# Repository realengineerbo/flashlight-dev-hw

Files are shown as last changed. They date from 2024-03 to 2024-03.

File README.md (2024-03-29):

# Flashlight Dev Board Hardware

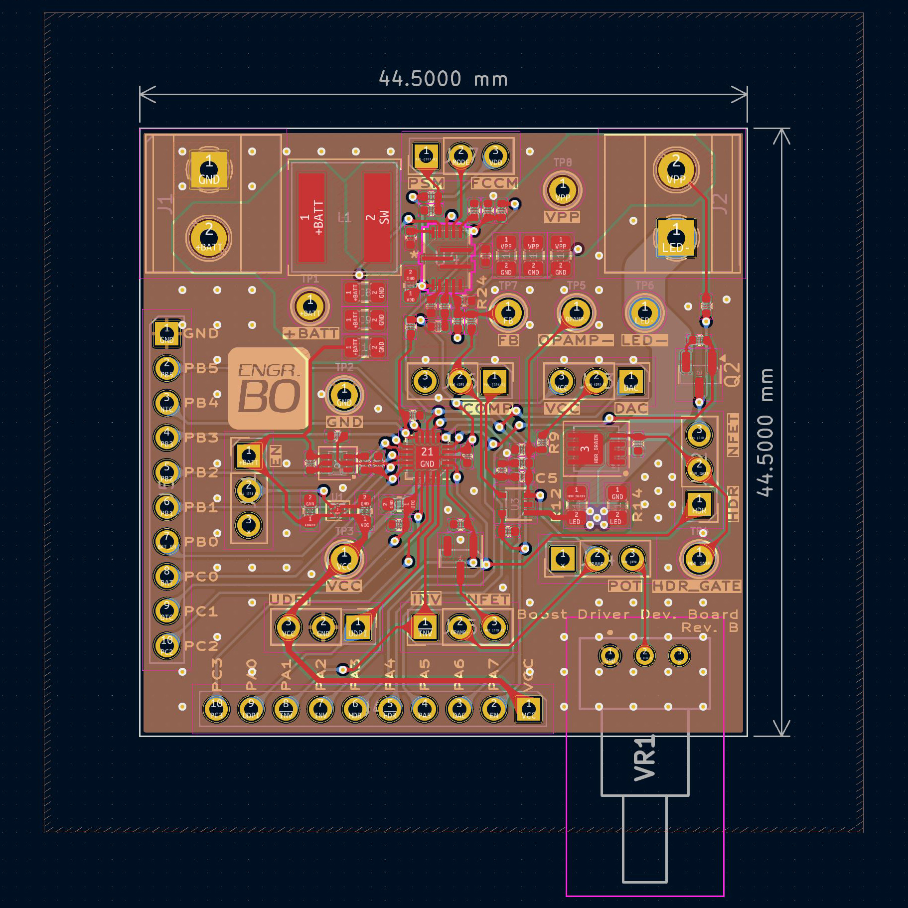
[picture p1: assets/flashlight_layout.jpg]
Dev board layout, rev. B

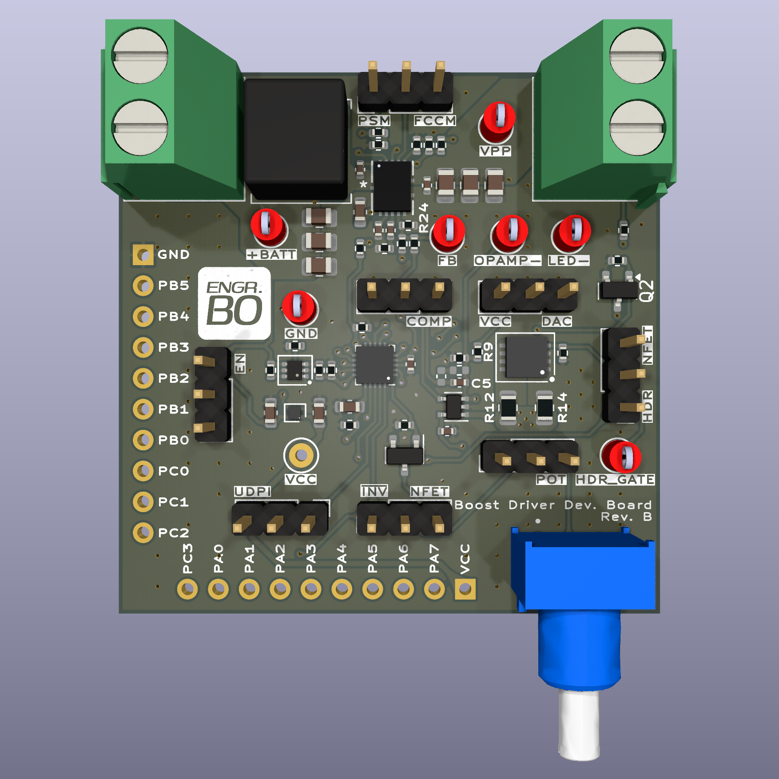
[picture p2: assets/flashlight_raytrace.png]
Dev board render, rev. B


## Introduction

This repository contains design files for the development board for a flashlight boost driver. The test firmware can be found in the [firmware repository](https://github.com/realengineerbo/flashlight-dev-fw).

Also included in the `scripts` subdirectory are Python scripts used to calculate component values during the design process, as well as generate the look-up table for brightness settings.

For a detailed explanation of this project, check out the [video series](https://www.youtube.com/playlist?list=PLYK5tmZIBWtEJjwAFE-49hSeELu9zoAmV) on the [Engineer Bo YouTube channel](https://youtube.com/@engineerbo).

## Features

The development board is design in [KiCad](https://www.kicad.org/), and features the following:

* ATtiny1616 microcontroller
* MP3432 boost converter
* LED current regulation
  * 1R and 10mR current sense resistances, selectable for high dynamic range (HDR)
  * ATtiny1616 DAC controlled current setpoint
  * Current regulation using TLV333/OPA333 op-amp and MP3432 feedback pin
* Power switch multi-click counting
* Temperature sensing
  * NTC thermistor
  * ATtiny1616 internal temperature sensor
* Battery voltage sensing with low current leakage
* Optional potentiometer for current setpoint (highly experimental)
* Test probe hooks
* Headers for all ATtiny1616 pins
* Many jumpers for testing different configurations

## Usage

This development board is meant to serve as a reference for anybody interested in learning about flashlight boost drivers. It's possible to build these boards, but assembly requires reasonable skill and involves less-than-friendly components e.g. DFN, QFN and many 0402 passives.

Instead, I recommend having a look at the schematics, and leave me a comment on [YouTube](https://www.youtube.com/playlist?list=PLYK5tmZIBWtEJjwAFE-49hSeELu9zoAmV) if you have any questions.

## Hardware Revisions

### Revision A

This is the original design built for testing, and includes a couple of issues:

* GPIO driven P-channel MOSFET for HDR MOSFET gate drive
* MP3432 UVLO not configured
* Wrong footprint for NTC thermistor

These issues and their fixes are explained in detail in the [video series](https://www.youtube.com/playlist?list=PLYK5tmZIBWtEJjwAFE-49hSeELu9zoAmV).

### Revision B

Revision B fixes the issues in Revision A:

* GPIO driven N-channel MOSFET for HDR MOSFET gate drive
* Added MP3432 UVLO

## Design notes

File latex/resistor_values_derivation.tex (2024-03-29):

\documentclass[landscape,twocolumn]{article} 

\usepackage{amsmath}
\usepackage[european resistors]{circuitikz}
\usepackage{geometry}
\usepackage{siunitx}

\geometry{left=4cm, right=4cm}
\pagestyle{empty}

\begin{document}

\begin{center}
    \scalebox{1.3}{
        \begin{circuitikz}

            % Draw resistors
            \draw (0,3) to [R, l=$R_a$, i_=$i_a$] (0,0);
            \draw (0,0) to [R, l=$R_b$, i_=$i_b$] (0,-3);
            \draw (3,0) to [R, l=$R_c$, i=$i_c$] (0,0);

            % Draw labels
            \draw (0,3) node[vcc]{$V_{out}$};

            \draw (0,-3) node[ground]{};

            \node [circ]() at (0,0) {};
            \draw (0,0) to (-1,0) node[ocirc]{};
            \draw (-2,0) node {$V_{FB}=1V$};

            \node [ocirc]() at (3,0) {};
            \draw (3.8,0) node {$V_{opamp}$};

        \end{circuitikz}
    }
\end{center}

\newpage

Where $R_a$ is known (e.g. $\SI{750}{\kilo\ohm}$), and:
\begin{gather*}
    V_{out} \propto V_{opamp}^{-1} \\
    V_{opamp,min}\le V_{opamp}\le V_{opamp,max} \\
    V_{out,min}\le V_{out}\le V_{out,max}
\end{gather*}

Currents through resistors:
\begin{align*}
    i_a & = \frac{V_{out} - 1}{R_a} \quad & i_b & = \frac{1}{R_b} \quad & i_c & = \frac{V_{opamp} - 1}{R_c}
\end{align*}

Using Kirchhoff's Current Law:
\begin{gather*}
    i_a + i_c = i_b \\
    \frac{V_{out} - 1}{R_a} + \frac{V_{opamp} - 1}{R_c} = \frac{1}{R_b}
\end{gather*}

Substituting:
\begin{gather*}
    \frac{V_{out,max} - 1}{R_a} + \frac{V_{opamp,min} - 1}{R_c} = \frac{1}{R_b} \\
    \frac{V_{out,min} - 1}{R_a} + \frac{V_{opamp,max} - 1}{R_c} = \frac{1}{R_b} \\
    \frac{V_{out,max} - 1}{R_a} + \frac{V_{opamp,min} - 1}{R_c} = \frac{V_{out,min} - 1}{R_a} + \frac{V_{opamp,max} - 1}{R_c}
\end{gather*}

Finally:
\begin{gather*}
    R_c = R_a\frac{V_{opamp,max} - V_{opamp,min}}{V_{out,max} - V_{out,min}}
\end{gather*}

\end{document}

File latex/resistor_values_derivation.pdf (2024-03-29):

## Vout

## Where Ra is known (e.g. 750 kΩ), and:

Vout ∝ V

−1
opamp

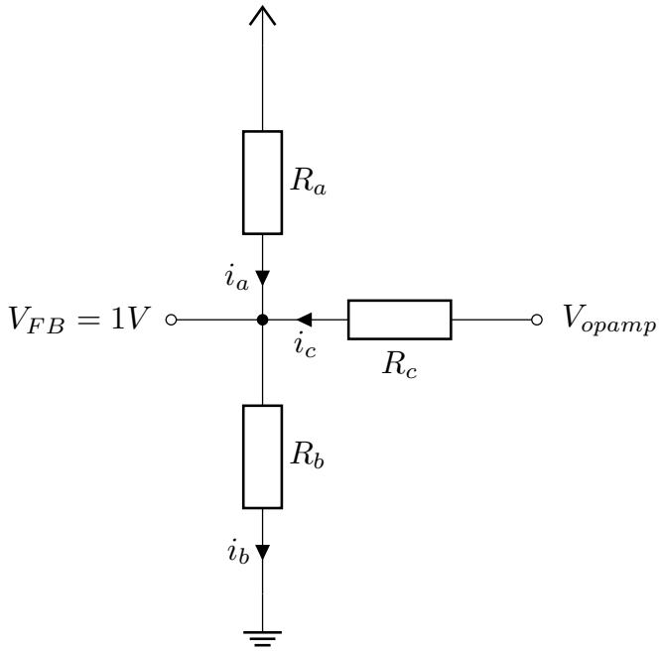
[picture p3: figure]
Vopamp

Vopamp,min ≤ Vopamp ≤ Vopamp,max

Vout,min ≤ Vout ≤ Vout,max

## Currents through resistors:

ia =

Vout − 1
Ra

ib =

1
Rb

ic =

Vopamp − 1
Rc

## Using Kirchhoff’s Current Law:

## ia + ic = ib

Vout − 1
Ra

+

Vopamp − 1
Rc

=

1
Rb

## Substituting:

Vout,max − 1
Ra

+

Vopamp,min − 1
Rc

=

1
Rb

Vout,min − 1
Ra

+

Vopamp,max − 1
Rc

=

1
Rb

Vout,max − 1
Ra

+

Vopamp,min − 1
Rc

=

Vout,min − 1
Ra

+

Vopamp,max − 1
Rc

## Finally:

## Rc = Ra

Vopamp,max − Vopamp,min

Vout,max − Vout,min

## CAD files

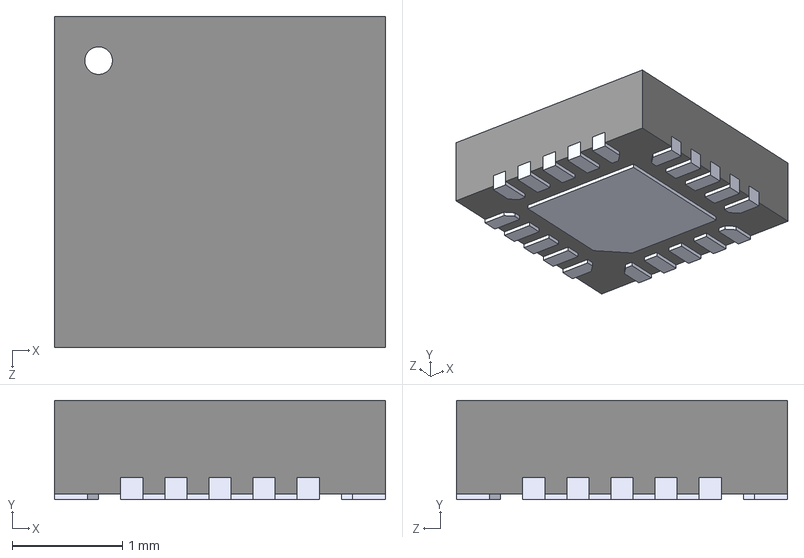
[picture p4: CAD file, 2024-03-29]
components/ATTINY1616-MFR.step
3.00 x 0.9 x 3.00 mm

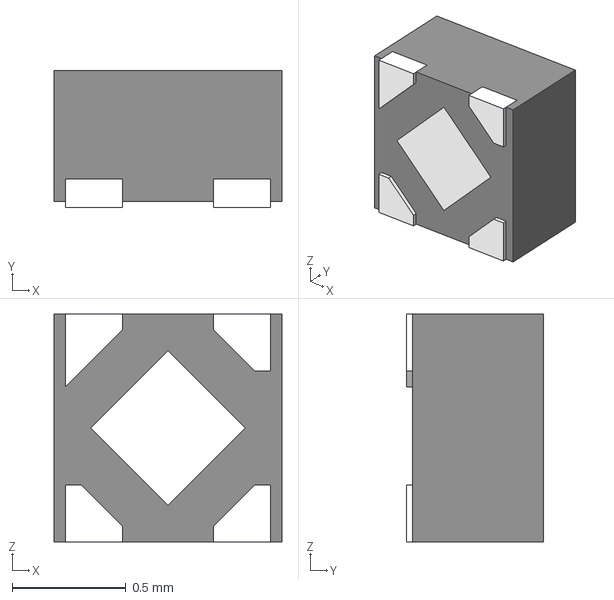
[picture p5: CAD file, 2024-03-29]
components/NCP114AMX330TCG.stp
1.00 x 0.6 x 1.00 mm

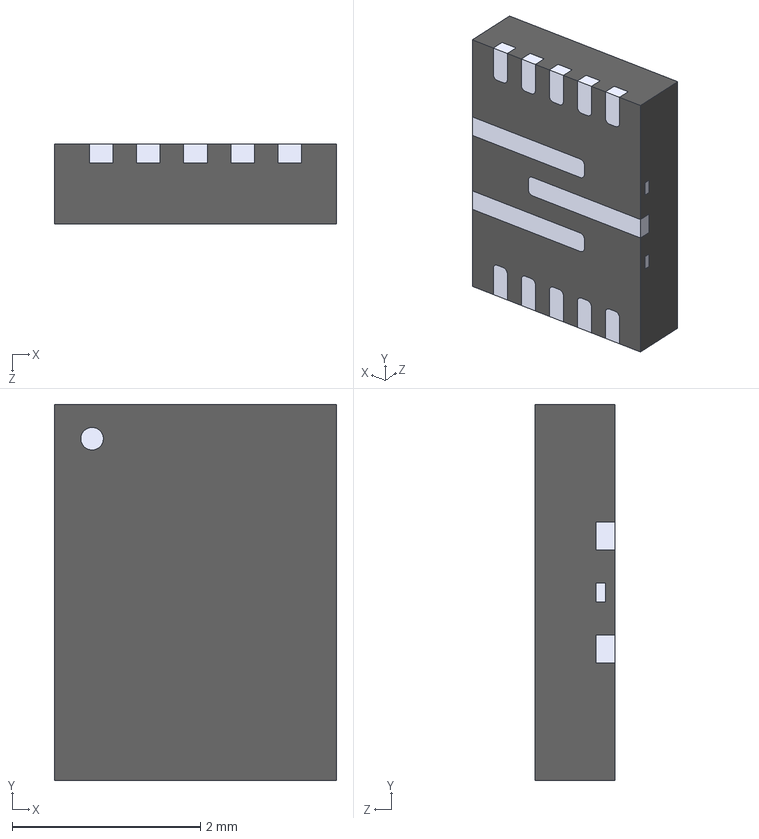
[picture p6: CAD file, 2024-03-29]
components/MP3429GL.step
3.00 x 4.00 x 0.85 mm

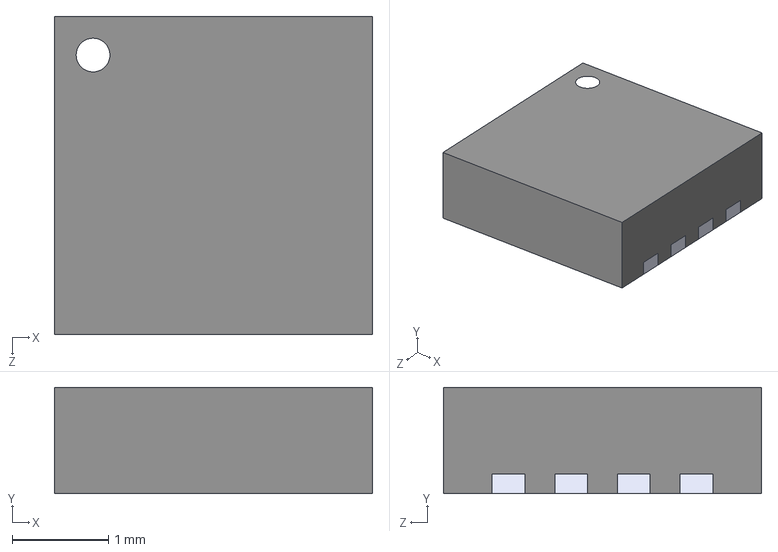
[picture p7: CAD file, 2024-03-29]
components/PG-TSDSON-8FL.step
3.30 x 1.10 x 3.30 mm

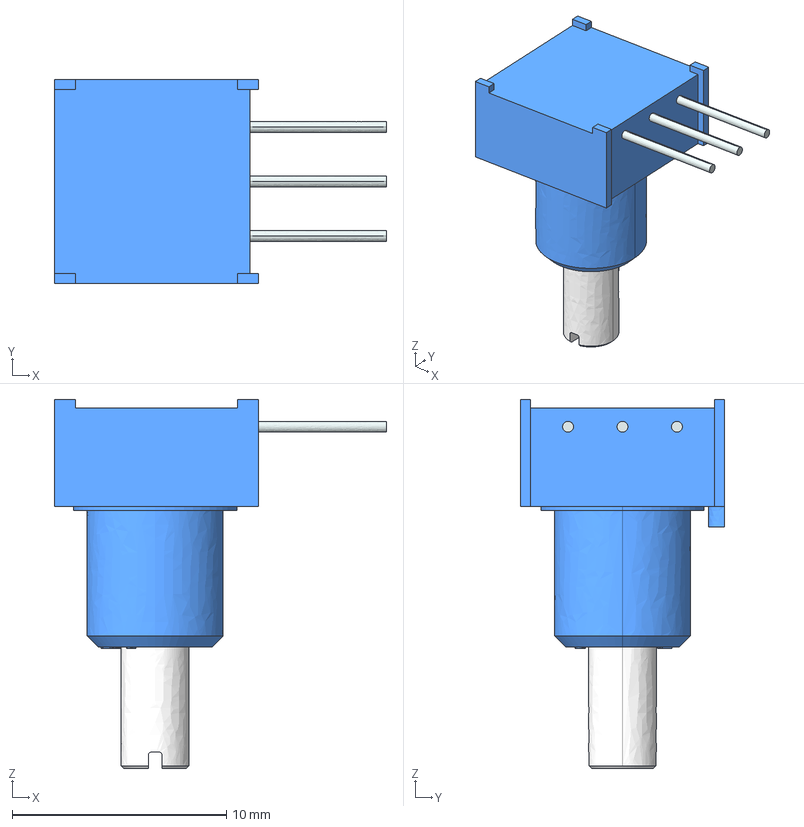
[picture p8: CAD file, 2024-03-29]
components/3310C-001-104L.stp
15.5 x 9.53 x 17.2 mm

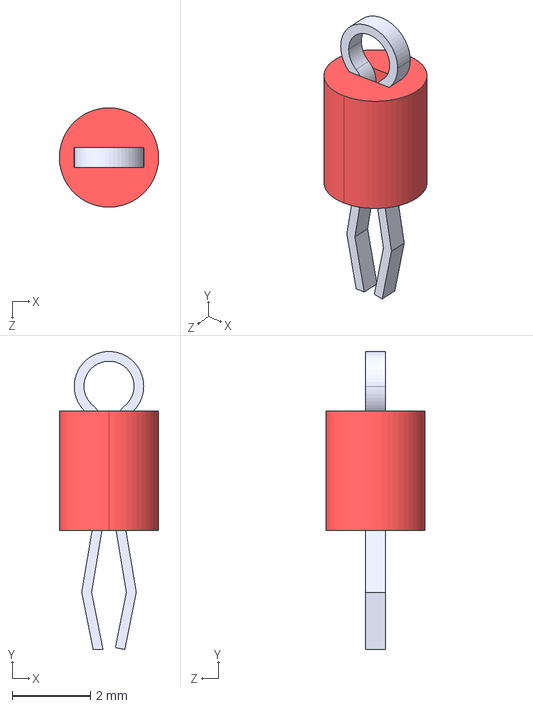
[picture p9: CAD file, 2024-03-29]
components/5000.step
2.54 x 7.62 x 2.54 mm

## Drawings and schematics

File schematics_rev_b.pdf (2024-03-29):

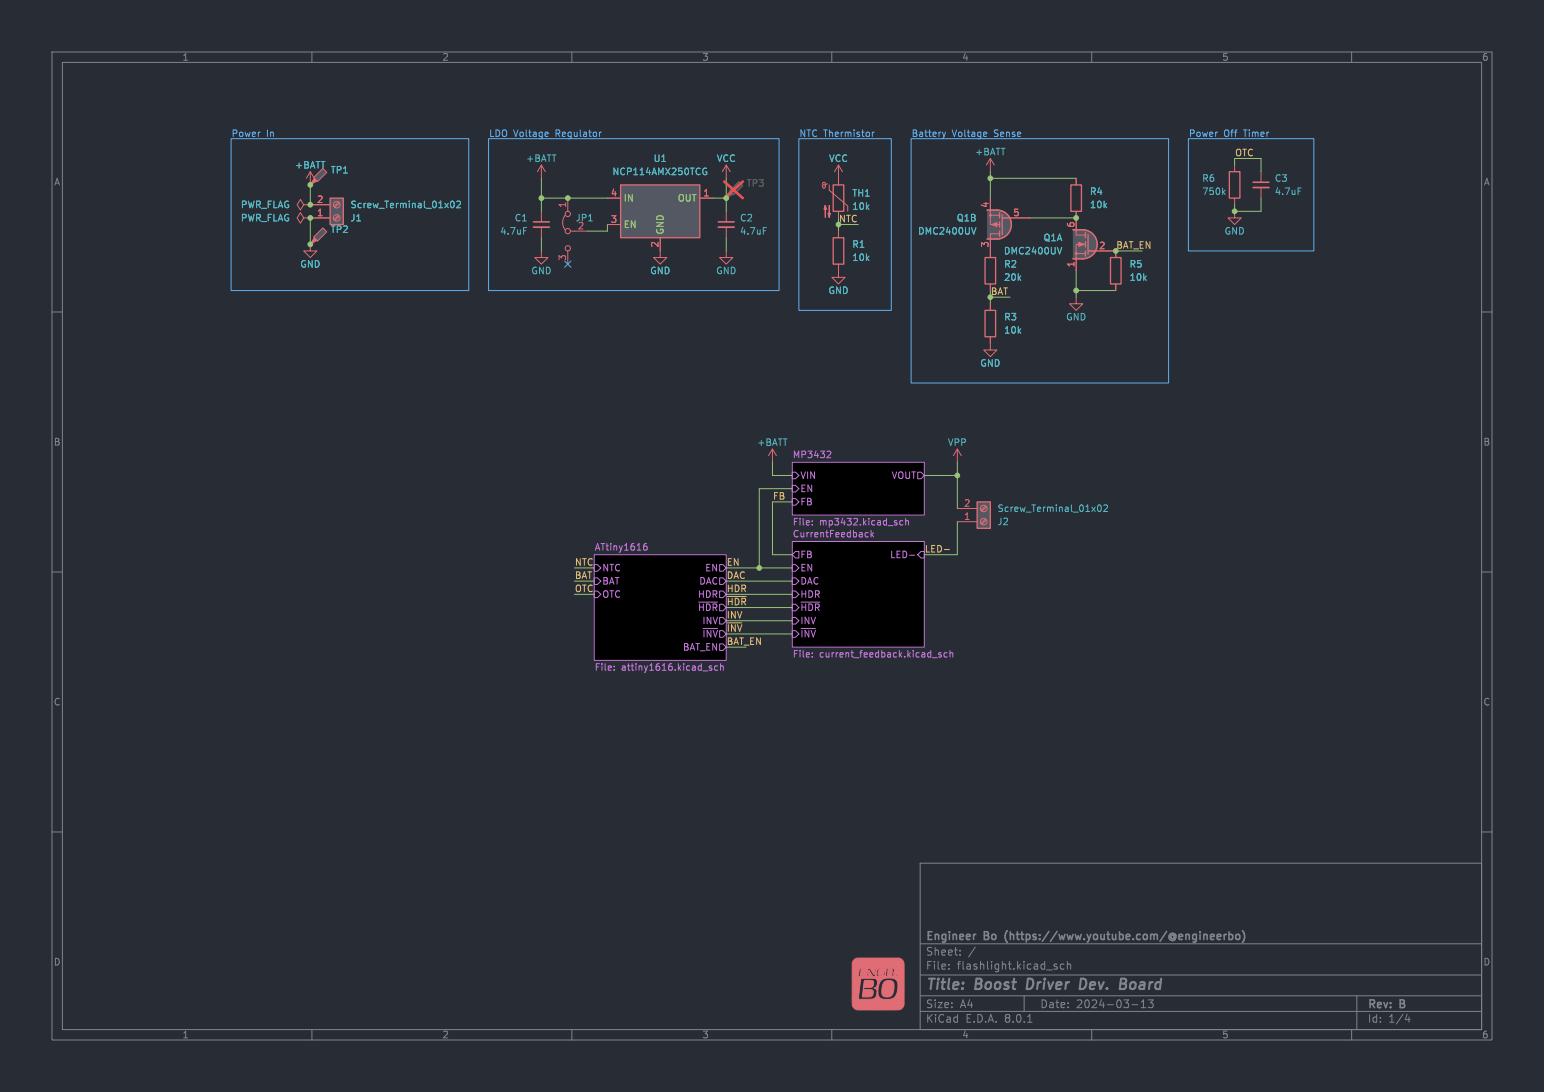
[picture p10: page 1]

Id: 1/4 Title: Boost Driver Dev. Board

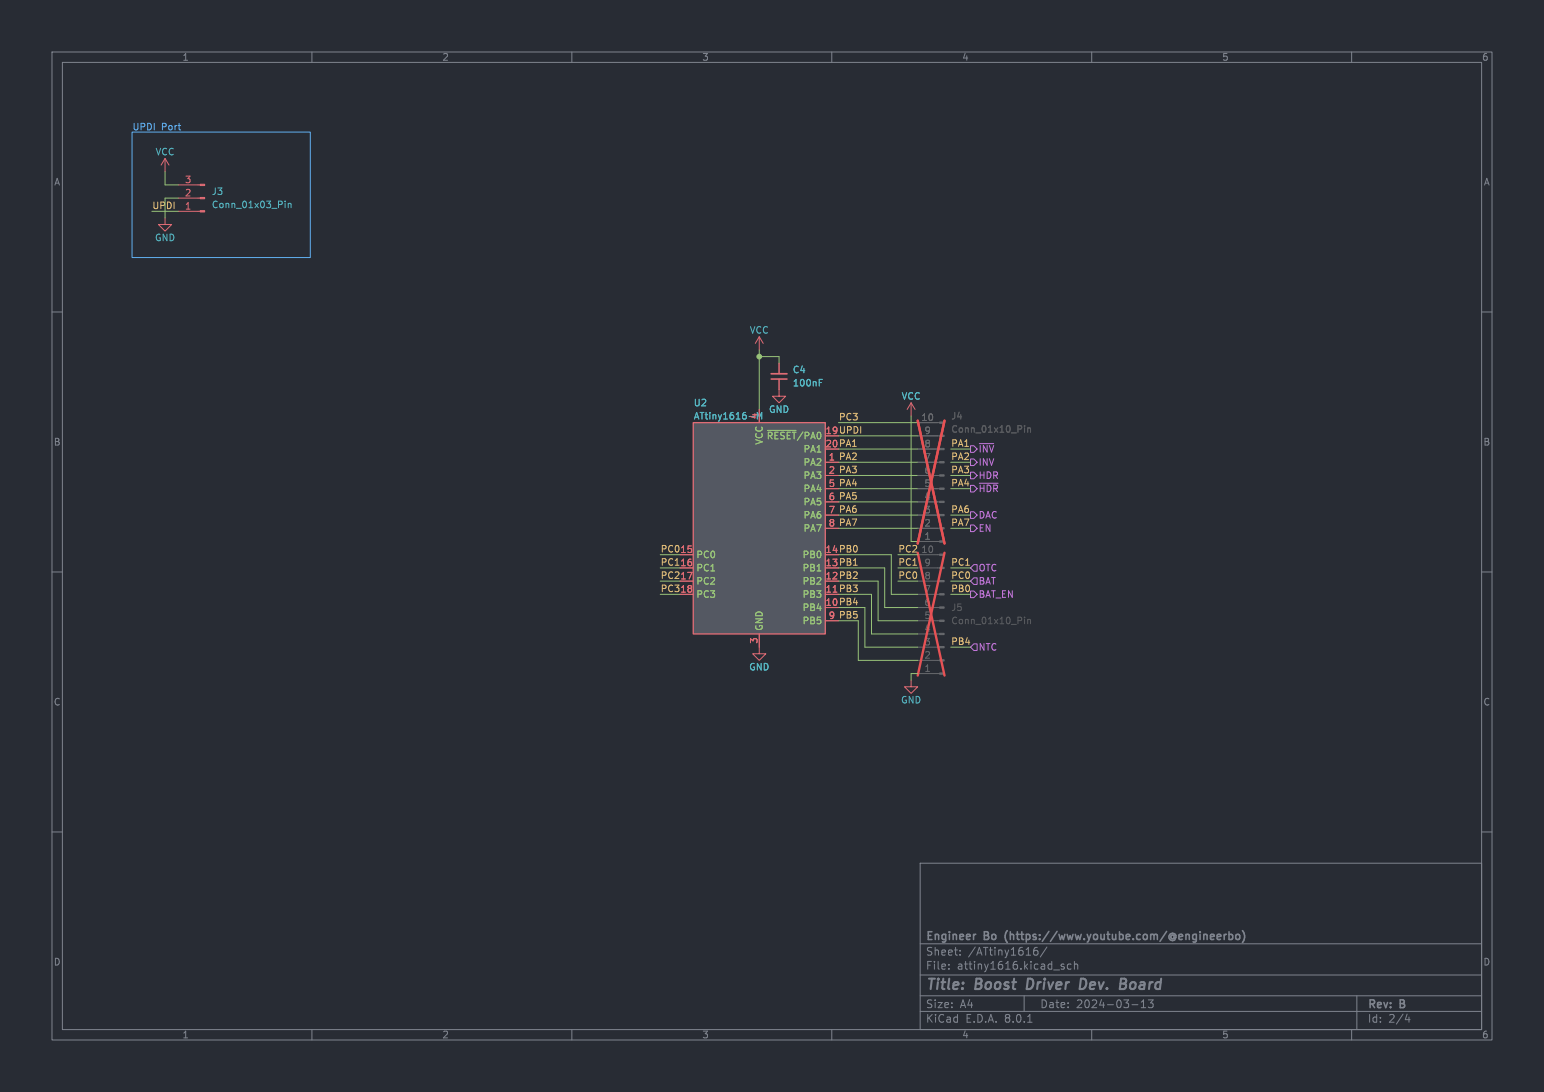
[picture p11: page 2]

File: attiny1616.kicad_sch Sheet: /ATtiny1616/
Id: 2/4 Title: Boost Driver Dev. Board

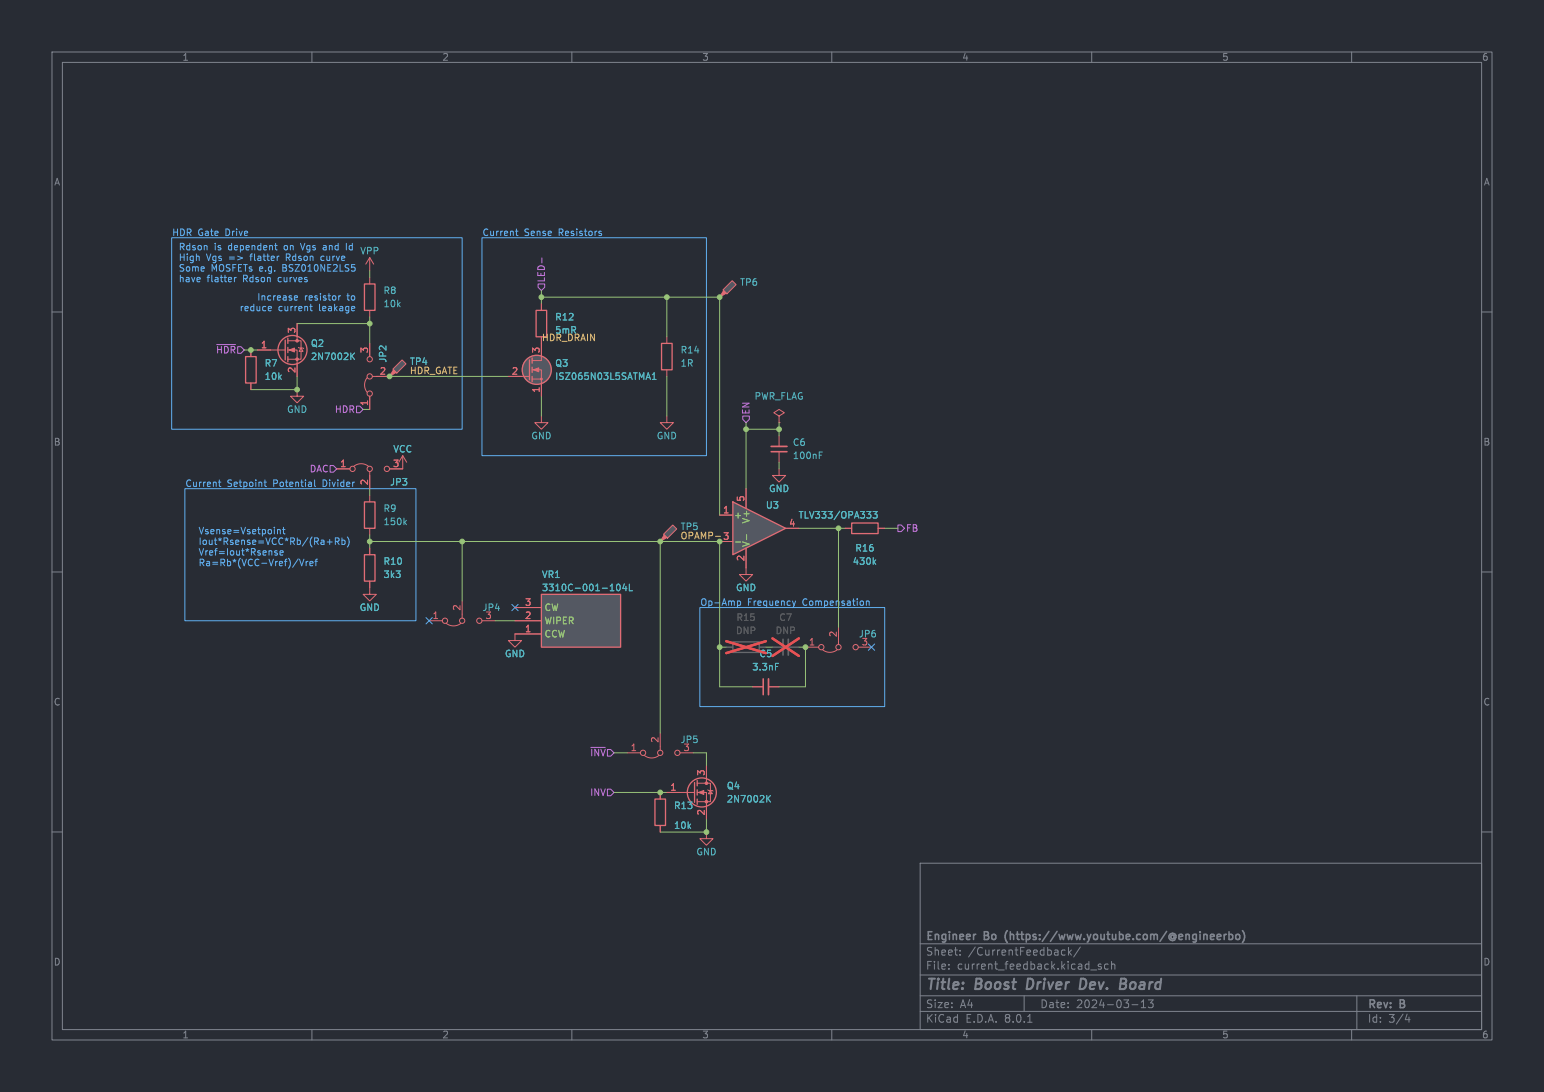
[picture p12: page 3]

Id: 3/4 Title: Boost Driver Dev. Board

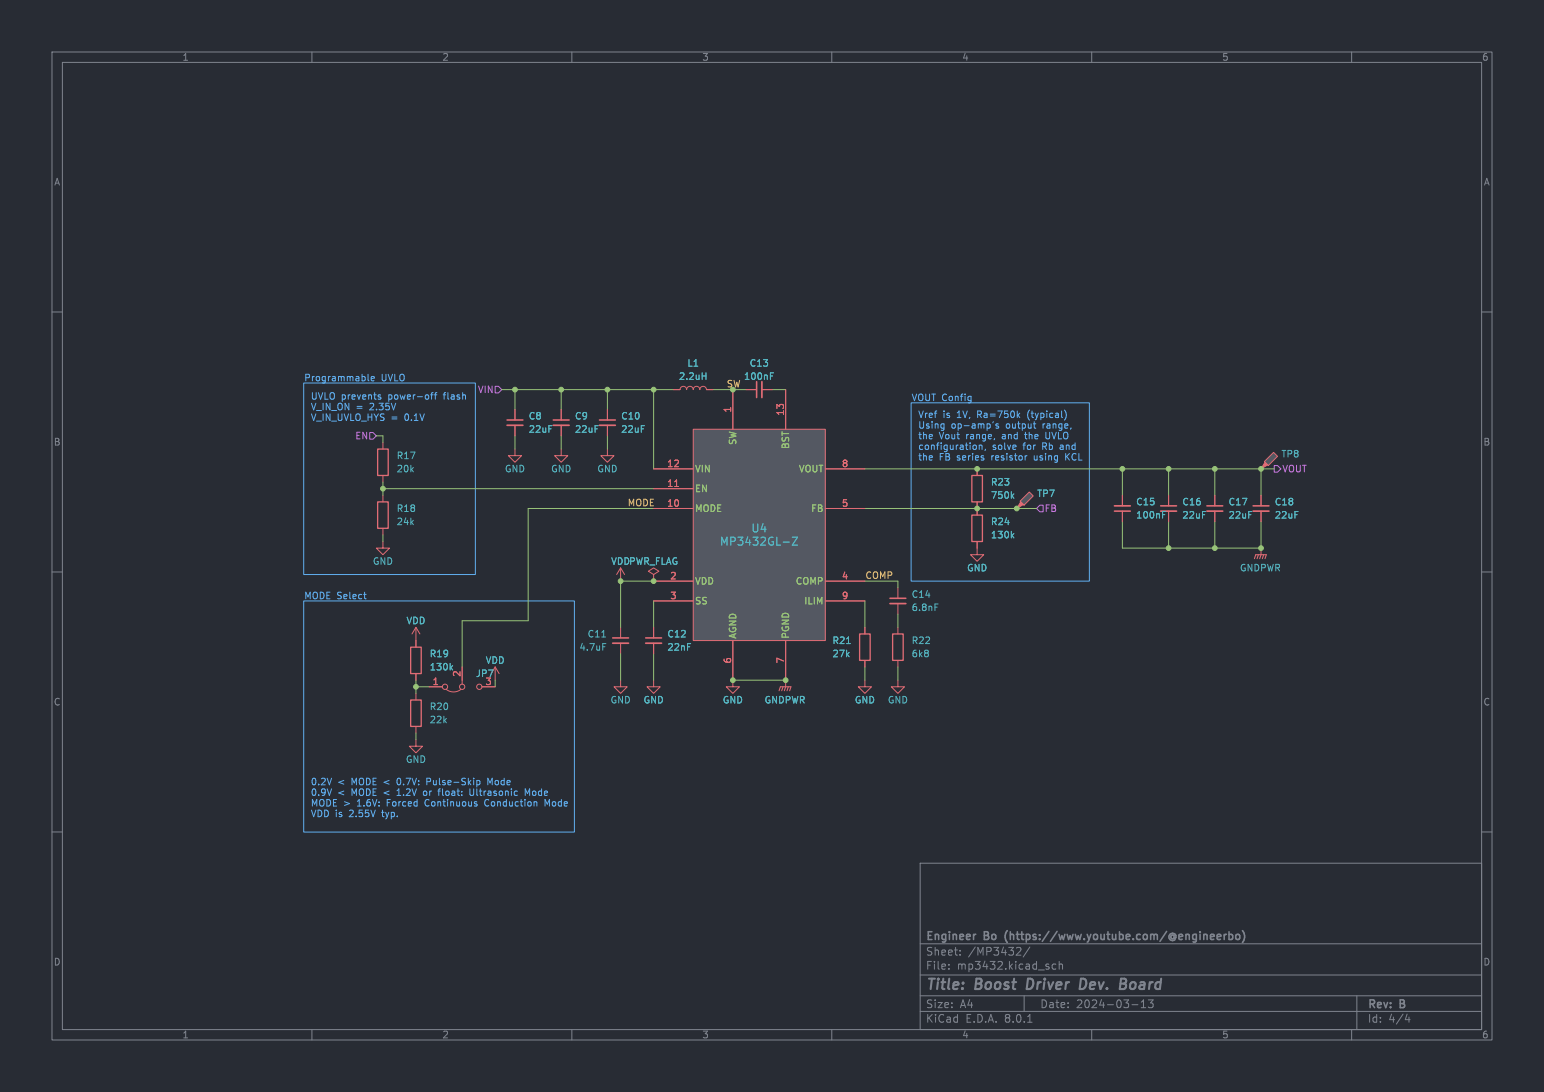
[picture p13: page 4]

1 MODE 10 EN 11 BST 13 VDD 2 SS 3 VOUT 8

the Vout range, and the UVLO

Id: 4/4 Title: Boost Driver Dev. Board

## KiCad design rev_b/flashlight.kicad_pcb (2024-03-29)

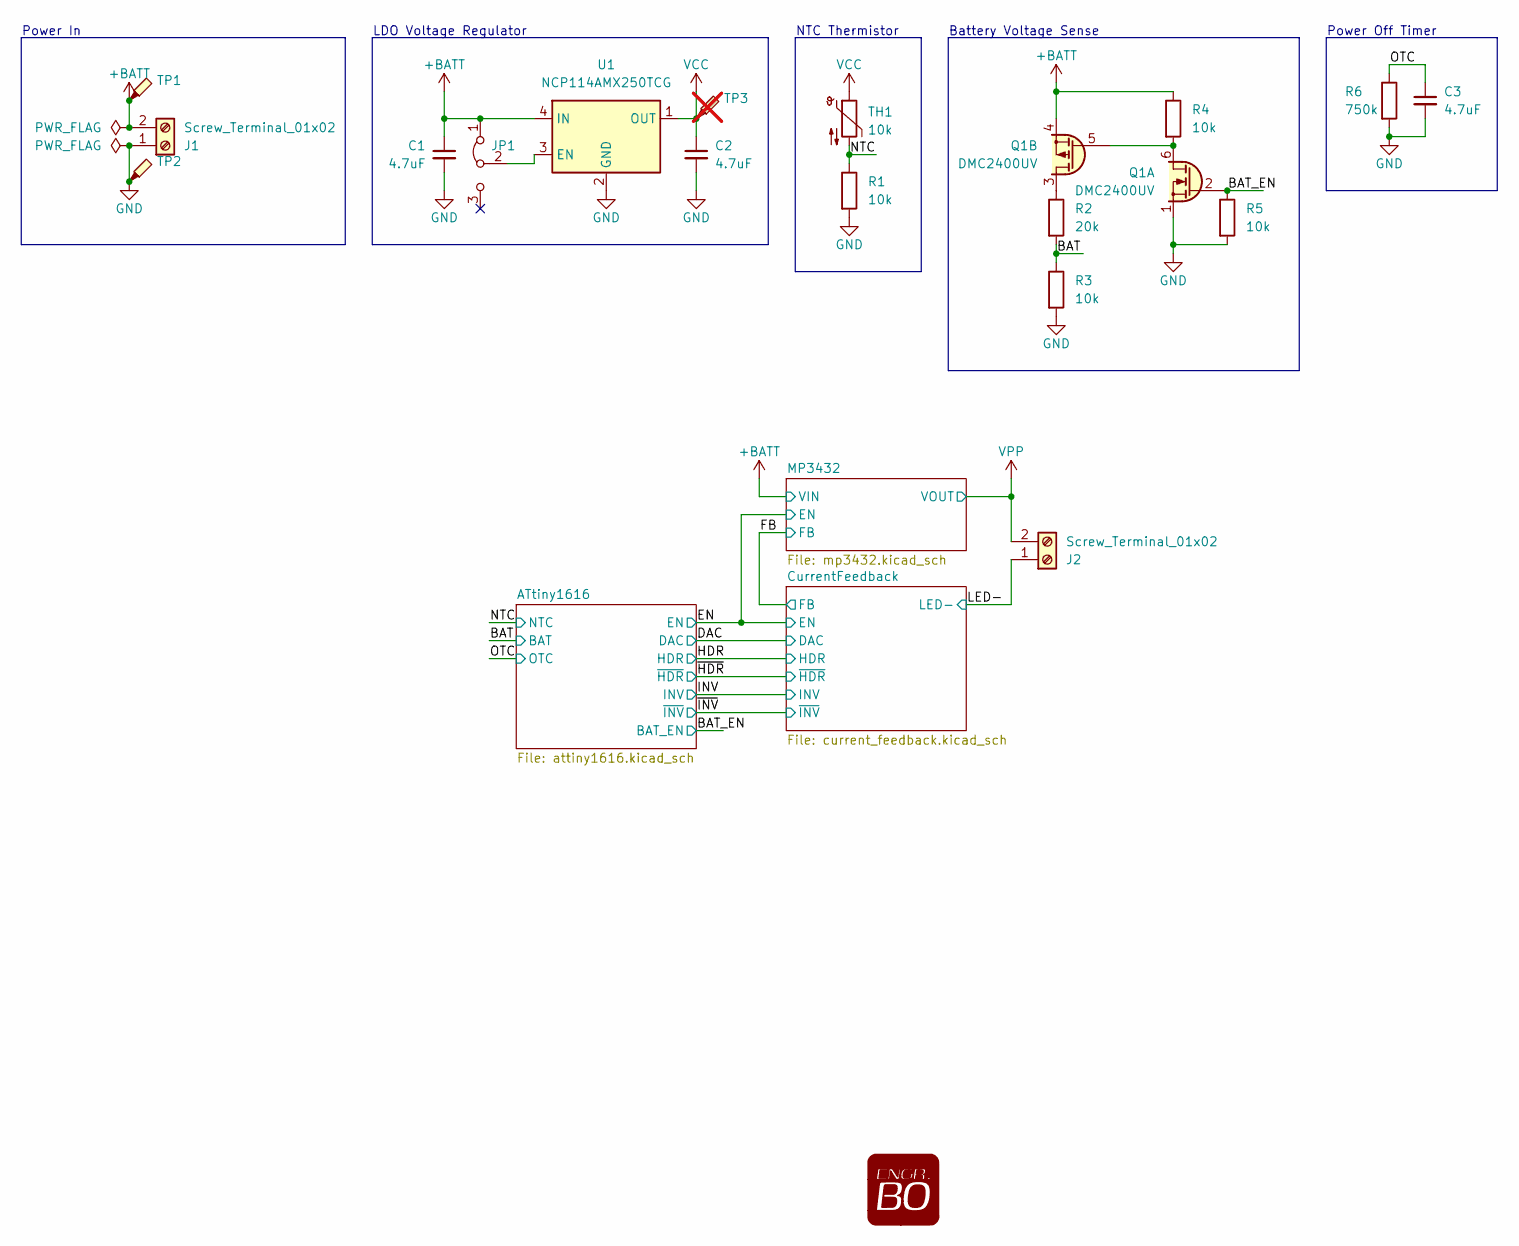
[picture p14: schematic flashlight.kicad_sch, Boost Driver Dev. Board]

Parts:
C1, C2, C3: 4.7uF; C_0603_1608Metric; Tolerance X5R; Voltage 16V
J1, J2: Screw_Terminal_01x02; TerminalBlock_Phoenix_MKDS-1,5-2_1x02_P5.00mm_Horizontal
JP1: Jumper_3_Bridged12; PinHeader_1x03_P2.54mm_Vertical
LOGO1: LOGO; logo_6mm
Q1: DMC2400UV; SOT-563
R1, R3, R4, R5: 10k; R_0402_1005Metric; Tolerance 1%
R2: 20k; R_0402_1005Metric; Tolerance 1%
R6: 750k; R_0402_1005Metric; Tolerance 1%
TH1: 10k; R_0402_1005Metric; PartNumber NCP15XH103F03RC
TP1, TP2: TestPoint_Probe; TestPoint_Keystone_5000-5004_Miniature; PartNumber RH-5000
TP3: TestPoint_Probe; TestPoint_Keystone_5000-5004_Miniature; PartNumber RH-5000; not fitted
U1: NCP114AMX250TCG; OnSemi_XDFN4-1EP_1.0x1.0mm_EP0.52x0.52mm; PartNumber NCP114AMX250TCG

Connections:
+BATT: C1.1, J1.2, JP1.1 (A), Q1.4 (S2), R4.1, TP1.1, U1.4 (IN); also elsewhere on the board
/BAT: R2.2, R3.1; also elsewhere on the board
/BAT_EN: Q1.2 (G1), R5.1; also elsewhere on the board
/LED-: J2.1; also elsewhere on the board
/NTC: R1.1, TH1.2; also elsewhere on the board
/OTC: C3.1, R6.1; also elsewhere on the board
GND: C1.2, C2.2, C3.2, J1.1, Q1.1 (S1), R1.2, R3.2, R5.2, R6.2, TP2.1, U1.2 (GND), U1.5 (GND); also elsewhere on the board
unnamed: JP1.2 (C), U1.3 (EN)
unnamed: Q1.5 (G2), Q1.6 (D1), R4.2
unnamed: Q1.3 (D2), R2.1
VCC: C2.1, TH1.1, TP3.1, U1.1 (OUT); also elsewhere on the board
VPP: J2.2; also elsewhere on the board

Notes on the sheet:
NTC Thermistor
Battery Voltage Sense
LDO Voltage Regulator
Power In
Power Off Timer

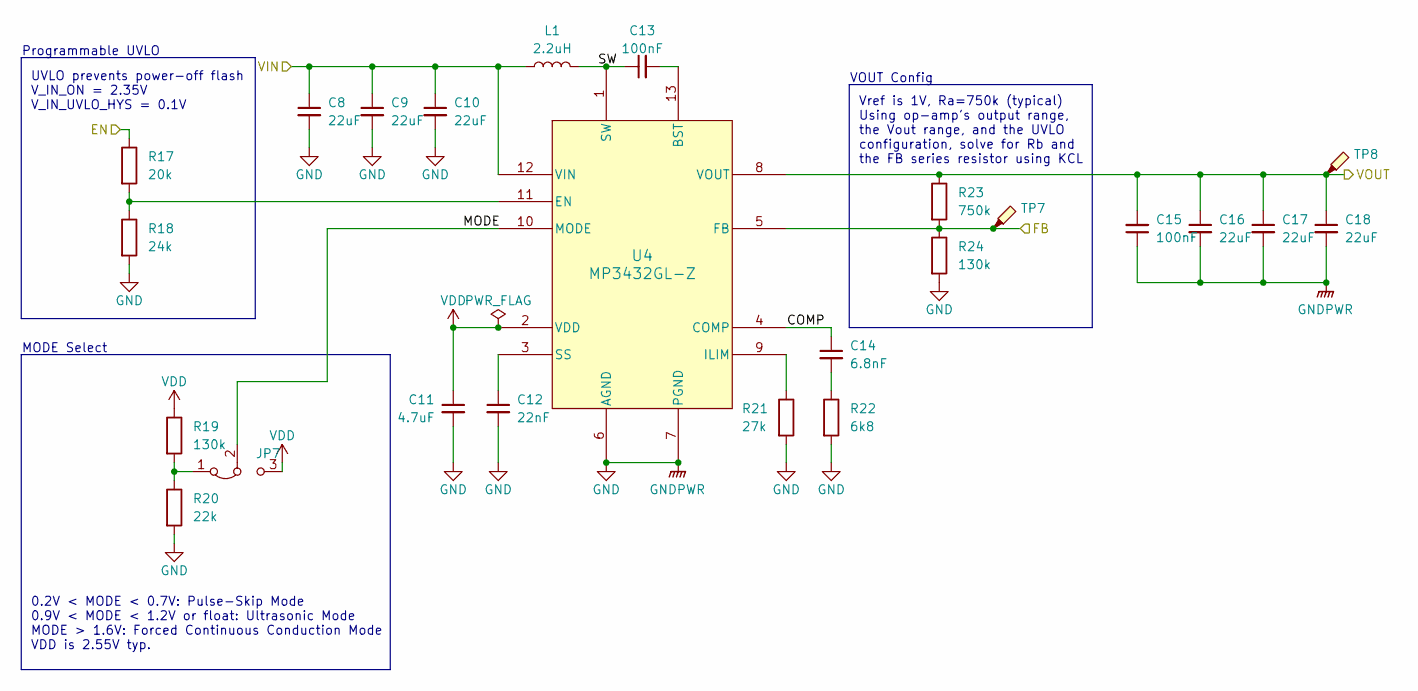
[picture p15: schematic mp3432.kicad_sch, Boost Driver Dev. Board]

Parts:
C8, C9, C10, C16, C17, C18: 22uF; C_0805_2012Metric; Tolerance X5R; Voltage 25V
C11: 4.7uF; C_0603_1608Metric; Tolerance X5R; Voltage 16V
C12: 22nF; C_0402_1005Metric
C13, C15: 100nF; C_0402_1005Metric
C14: 6.8nF; C_0402_1005Metric
JP7: Jumper_3_Bridged12; PinHeader_1x03_P2.54mm_Vertical
L1: 2.2uH; L_Coilcraft_XAL7070-XXX; PartNumber XAL7070-222MEC
R17: 20k; R_0402_1005Metric; Tolerance 1%
R18: 24k; R_0402_1005Metric; Tolerance 1%
R19, R24: 130k; R_0402_1005Metric; Tolerance 1%
R20: 22k; R_0402_1005Metric; Tolerance 1%
R21: 27k; R_0402_1005Metric; Tolerance 1%
R22: 6k8; R_0402_1005Metric; Tolerance 1%
R23: 750k; R_0402_1005Metric; Tolerance 1%
TP7, TP8: TestPoint_Probe; TestPoint_Keystone_5000-5004_Miniature; PartNumber RH-5000
U4: MP3432GL-Z; QFN-13_MP3431_MNP; PartNumber MP3432GL-Z

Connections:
+BATT: C8.1, C9.1, C10.1, L1.1, U4.12 (VIN); also elsewhere on the board
/EN: R17.1; also elsewhere on the board
/FB: R23.2, R24.1, TP7.1, U4.5 (FB); also elsewhere on the board
/MP3432/COMP: C14.1, U4.4 (COMP)
/MP3432/MODE: JP7.2 (C), U4.10 (MODE)
/MP3432/SW: C13.1, L1.2, U4.1 (SW)
GND: C8.2, C9.2, C10.2, C11.2, C12.2, C15.1, C16.2, C17.2, C18.2, R18.2, R20.2, R21.2, R22.2, R24.2, U4.6 (AGND), U4.7 (PGND); also elsewhere on the board
unnamed: C14.2, R22.1
unnamed: JP7.1 (A), R19.2, R20.1
unnamed: C13.2, U4.13 (BST)
unnamed: R17.2, R18.1, U4.11 (EN)
unnamed: R21.1, U4.9 (ILIM)
unnamed: C12.1, U4.3 (SS)
VDD: C11.1, JP7.3 (B), R19.1, U4.2 (VDD)
VPP: C15.2, C16.1, C17.1, C18.1, R23.1, TP8.1, U4.8 (VOUT); also elsewhere on the board

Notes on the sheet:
Vref is 1V, Ra=750k (typical) Using op-amp's output range, the Vout range, and the UVLO configuration, solve for Rb and the FB series resistor using KCL
0.2V < MODE < 0.7V: Pulse-Skip Mode 0.9V < MODE < 1.2V or float: Ultrasonic Mode MODE > 1.6V: Forced Continuous Conduction Mode VDD is 2.55V typ.
MODE Select
UVLO prevents power-off flash V_IN_ON = 2.35V V_IN_UVLO_HYS = 0.1V
Programmable UVLO
VOUT Config

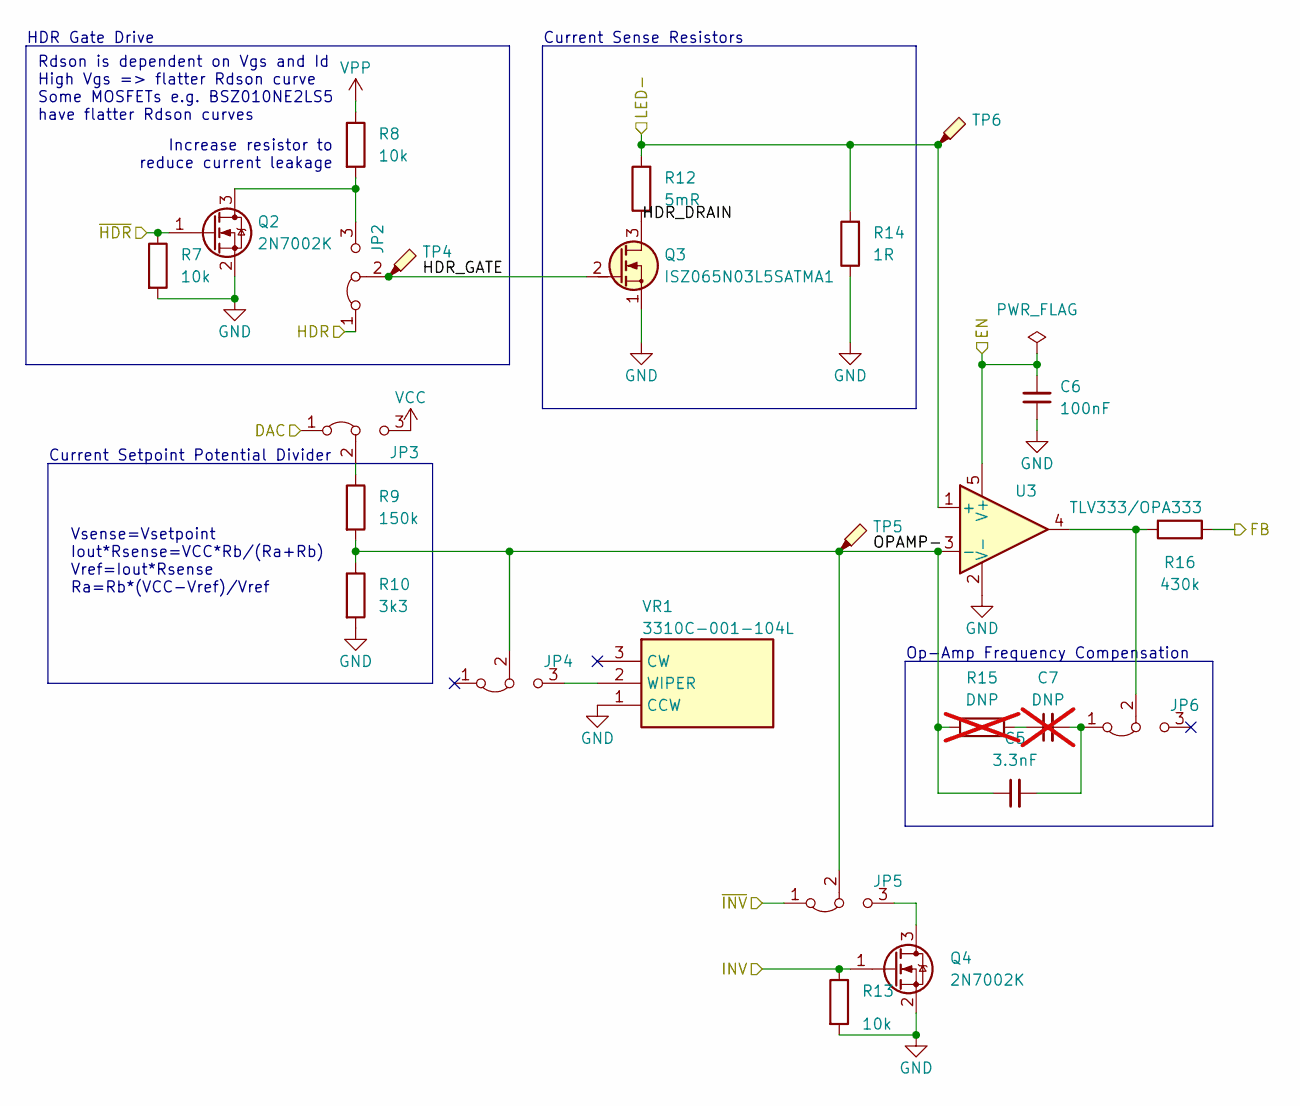
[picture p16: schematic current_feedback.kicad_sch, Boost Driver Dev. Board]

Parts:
C5: 3.3nF; C_0402_1005Metric; Tolerance C0G
C6: 100nF; C_0402_1005Metric
C7: DNP; C_0402_1005Metric; Tolerance C0G; not fitted
JP2, JP3, JP4, JP5, JP6: Jumper_3_Bridged12; PinHeader_1x03_P2.54mm_Vertical
Q2, Q4: 2N7002K; SOT-23
Q3: ISZ065N03L5SATMA1; Infineon_PG_TSDSON-8_FL; PartNumber ISZ065N03L5SATMA1
R7, R8, R13: 10k; R_0402_1005Metric; Tolerance 1%
R9: 150k; R_0402_1005Metric; Tolerance 1%
R10: 3k3; R_0402_1005Metric; Tolerance 1%
R12: 5mR; R_0805_2012Metric; Tolerance 1%
R14: 1R; R_0805_2012Metric; Tolerance 1%
R15: DNP; R_0402_1005Metric; Tolerance 1%; not fitted
R16: 430k; R_0402_1005Metric; Tolerance 1%
TP4, TP5, TP6: TestPoint_Probe; TestPoint_Keystone_5000-5004_Miniature; PartNumber RH-5000
U3: TLV333/OPA333; SOT-353_SC-70-5; PartNumber TLV333IDCKR
VR1: 3310C-001-104L; 3310C001503L; Mouser Part Number 652-3310C-001-104L

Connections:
/CurrentFeedback/HDR_DRAIN: Q3.3 (D), R12.1
/CurrentFeedback/HDR_GATE: JP2.2 (C), Q3.2 (G), TP4.1
/CurrentFeedback/OPAMP-: C5.1, JP4.2 (C), JP5.2 (C), R9.2, R10.1, R15.1, TP5.1, U3.3 (-)
/DAC: JP3.1 (A); also elsewhere on the board
/EN: C6.2, U3.5 (V+); also elsewhere on the board
/FB: R16.2; also elsewhere on the board
/HDR: JP2.1 (A); also elsewhere on the board
/INV: Q4.1 (G), R13.1; also elsewhere on the board
/LED-: R12.2, R14.2, TP6.1, U3.1 (+); also elsewhere on the board
/~HDR: Q2.1 (G), R7.1; also elsewhere on the board
/~INV: JP5.1 (A); also elsewhere on the board
GND: C6.1, Q2.2 (S), Q3.1 (S), Q4.2 (S), R7.2, R10.2, R13.2, R14.1, U3.2 (V-), VR1.1 (CCW); also elsewhere on the board
unnamed: C7.1, R15.2
unnamed: JP2.3 (B), Q2.3 (D), R8.2
unnamed: JP3.2 (C), R9.1
unnamed: JP4.3 (B), VR1.2 (WIPER)
unnamed: JP5.3 (B), Q4.3 (D)
unnamed: C5.2, C7.2, JP6.1 (A)
unnamed: JP6.2 (C), R16.1, U3.4
VCC: JP3.3 (B); also elsewhere on the board
VPP: R8.1; also elsewhere on the board

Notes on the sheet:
Current Setpoint Potential Divider
HDR Gate Drive
Vsense=Vsetpoint Iout*Rsense=VCC*Rb/(Ra+Rb) Vref=Iout*Rsense Ra=Rb*(VCC-Vref)/Vref
Increase resistor to reduce current leakage
Rdson is dependent on Vgs and Id High Vgs => flatter Rdson curve Some MOSFETs e.g. BSZ010NE2LS5 have flatter Rdson curves
Op-Amp Frequency Compensation
Current Sense Resistors

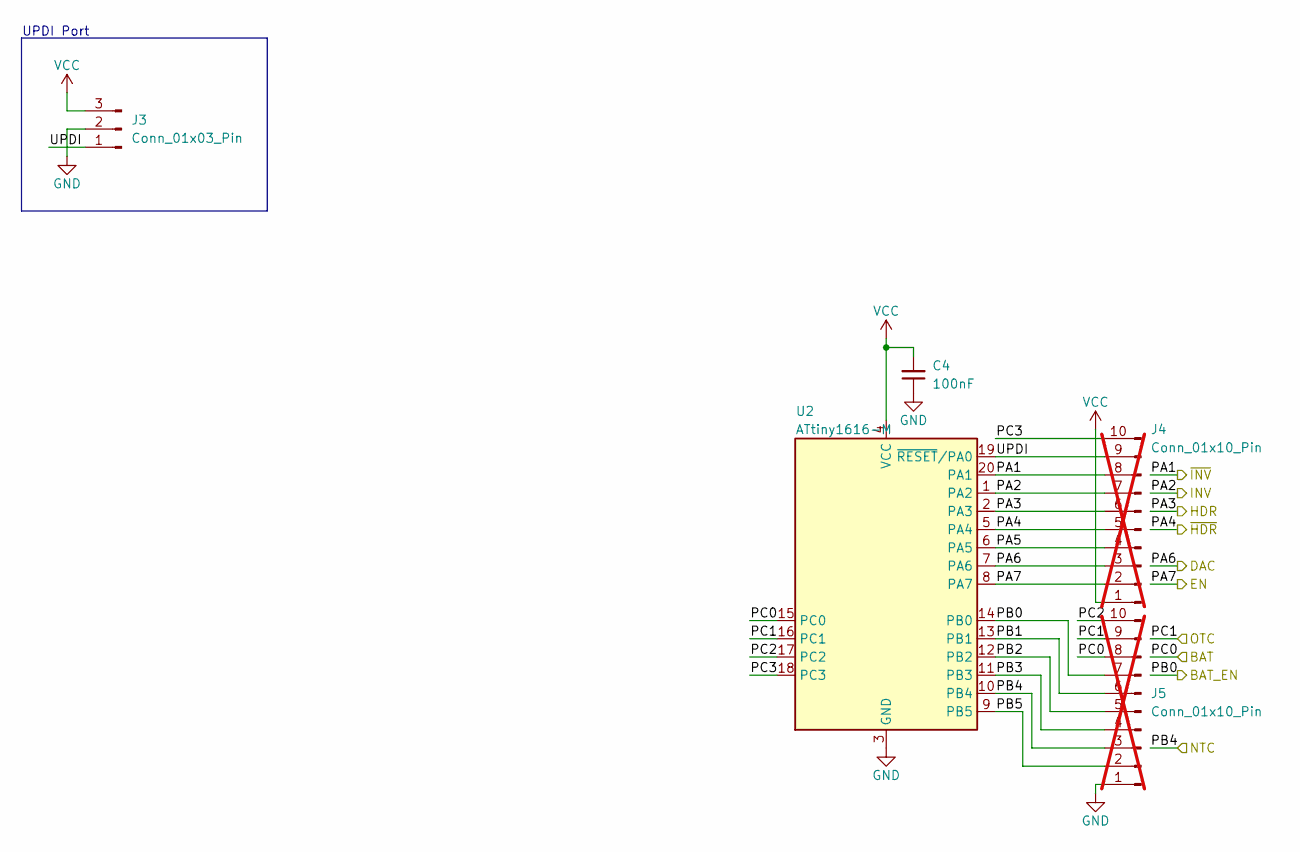
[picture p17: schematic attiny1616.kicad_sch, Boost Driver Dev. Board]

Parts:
C4: 100nF; C_0402_1005Metric
J3: Conn_01x03_Pin; PinHeader_1x03_P2.54mm_Vertical
J4, J5: Conn_01x10_Pin; PinHeader_1x10_P2.54mm_Vertical; not fitted
U2: ATtiny1616-M; VQFN-20-1EP_3x3mm_P0.4mm_EP1.7x1.7mm; PartNumber ATTINY1616-MNR

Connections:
/ATtiny1616/PA5: J4.4, U2.6 (PA5)
/ATtiny1616/PB1: J5.6, U2.13 (PB1)
/ATtiny1616/PB2: J5.5, U2.12 (PB2)
/ATtiny1616/PB3: J5.4, U2.11 (PB3)
/ATtiny1616/PB5: J5.2, U2.9 (PB5)
/ATtiny1616/PC2: J5.10, U2.17 (PC2)
/ATtiny1616/PC3: J4.10, U2.18 (PC3)
/ATtiny1616/UPDI: J3.1, J4.9, U2.19 (~RESET/PA0)
/BAT: J5.8, U2.15 (PC0); also elsewhere on the board
/BAT_EN: J5.7, U2.14 (PB0); also elsewhere on the board
/DAC: J4.3, U2.7 (PA6); also elsewhere on the board
/EN: J4.2, U2.8 (PA7); also elsewhere on the board
/HDR: J4.6, U2.2 (PA3); also elsewhere on the board
/INV: J4.7, U2.1 (PA2); also elsewhere on the board
/NTC: J5.3, U2.10 (PB4); also elsewhere on the board
/OTC: J5.9, U2.16 (PC1); also elsewhere on the board
/~HDR: J4.5, U2.5 (PA4); also elsewhere on the board
/~INV: J4.8, U2.20 (PA1); also elsewhere on the board
GND: C4.1, J3.2, J5.1, U2.3 (GND), U2.21 (GND); also elsewhere on the board
VCC: C4.2, J3.3, J4.1, U2.4 (VCC); also elsewhere on the board

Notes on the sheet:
UPDI Port

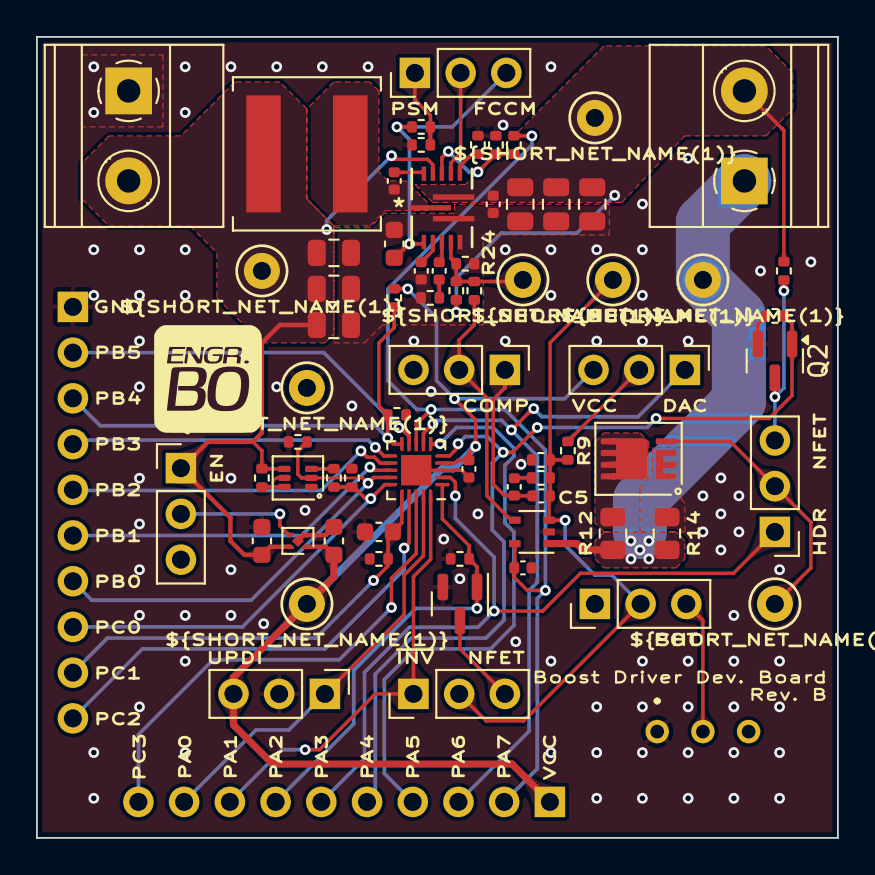
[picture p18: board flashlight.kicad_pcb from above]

Board: 4 copper layers, 44.5 x 44.5 mm, 73 parts (0 on the bottom side), 47 nets.
